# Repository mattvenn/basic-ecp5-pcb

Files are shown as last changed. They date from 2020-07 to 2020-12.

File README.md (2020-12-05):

## ECP5 FPGA dev board

* Make an ECP5 FPGA dev board
* Keep it super simple and cheap
* Configured by on-board FLASH or direct with a Raspberry Pi
* 6 PMODs, 2 buttons, 2 LEDs, FLASH for configuration bitstreams.
* buttons are active low, LEDs are active low.

There is also an iCE40 version of this board: https://github.com/mattvenn/first-fpga-pcb

## What a Lattice ecp5 FPGA needs

Check ECP5 family datasheet for more information.

* A clock input. Has to be provided by an oscillator, it doesn't have a crystal driver. Has to go to a PCLK pad
* 1.1v core supply for the internal logic. Should supply at least 600mA
* 2.5v auxiliary power supply. Should supply 10mA
* 3.3v IO supply for the IO pins. In this design, all banks of IO have the same supply. Same PSU is used for all PMODs, and is rated at 1A.
* Get configured over SPI interface. This can be done directly by a microcontroller or a computer, or the bitstream can be programmed into some FLASH, and the FPGA will read it at boot. If FLASH isn't provided then the bitstream needs to be programmed at every power up or configuration reset. See sysconfig documentation for more info.
* Decoupling capacitors for each IO bank.

## PCB

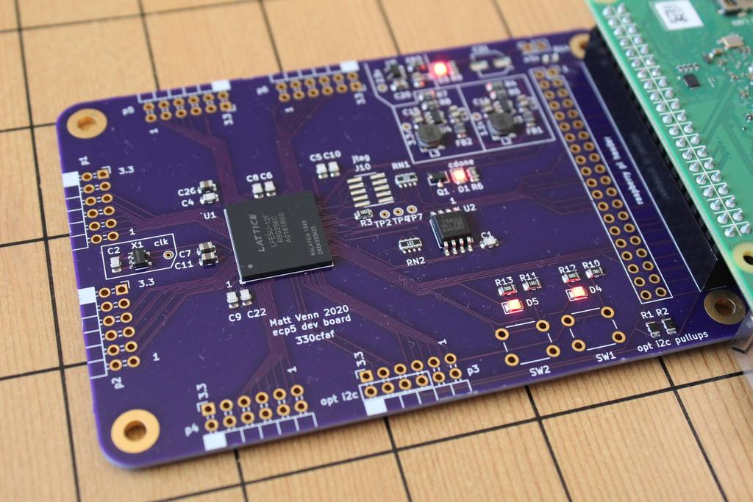
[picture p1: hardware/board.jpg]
board


* [Schematic](hardware/schematic.pdf)
* [OHSPark project](https://oshpark.com/shared_projects/pCsPoHNi) 
* [Gerbers](hardware/hardware/basic-ecp5-pcb-2020-07-20-fab.zip)

* 4 layer board stackup: signal, gnd, 3.3v, signal

## BOM

* FPGA ecp5 12k (LFE5U-12F-6BG256C) or 45k (LFE5U-45F-6BG256C) part, 14mm bga with 256 pins, 0.8mm pitch 
* 2 x TLV62568 DC/DC switchers for core (1.1v) and IO (3.3v).
* 2.5v reg TLV73325PDBVT
* 16MHz oscillator SIT2001BI-S2-33N-16.000000G
* 16MB FLASH W25Q128JVSIM (same as icebreaker)

## Design Review

* core supply (1.1v) is now DC/DC for 1A using TLV62568
* pmod and IO supply is now DC/DC for 1A using TLV62568
* move ferrite beads to input side of psu
* pullups on io2/3 of flash
* pulldown on tclk of jtag
* fix vias under bga by moving to 0.25mm drill 0.45mm annular ring
* add more ground vias under BGA

## Errata

* Add missing qspi to the Pi to be able to program bitstream faster.
* configuration bits for FPGA should be tied to gnd not through a 10k resistor. The voltage is about 1v, so might
  be a little close to the threshold of the 3.3v IOBANK supply. Replace with 0Ohm resistors? Or just tie to gnd?
* used IS25LP016D-JBLE as flash, but it has problems with enabling QE for QSPI. Relace with the model used on icebreaker
* ecp5 SPI clock pin can't be used as an input, so have to [add a bodge wire](https://github.com/mattvenn/basic-ecp5-pcb/issues/3) for SPI peripheral comms with Pi. See the test-spi-clk-in branch for a workaround.

## RPi connection info

See [test/mv_ecp.lpf](test/mv_ecp.lpf) for FPGA pinning. The following are the physical pins on the raspberry pi:

* serial: TX, RX on pins 8 and 10
* I2C: bitbanged on pins 38 and 40. Optional pullup resistors R1 & R2. Need to set up in boot/config.txt
* GPIOs: pins 31, 32, 33, 36.
* SPI: SDO, SDI, CLK, CE0 on pins 19, 21, 23, 24. These are connected to the onboard FLASH for bitstream config.
* Extra SPI CE1: pin 26 

### RPi Gotchas

* [fomu_flash will leave the SPI device in an unusable state](https://github.com/im-tomu/fomu-flash/issues/8). Run `sudo rmmod spi_bcm2835 && sudo modprobe spi_bcm2835` to reset it.
* connected I2C pins are just GPIOs. I have found the Pi's I2C hardware unusable, so always use the slower bitbanged version. 
  To enable add this to /boot/config.txt: `dtoverlay=i2c-gpio,i2c_gpio_sda=21,i2c_gpio_scl=20,i2c_gpio_delay_us=8,bus=3`

## Test: 

Simple [test](test/blinky.v) connects buttons to LEDs and toggles all other pins every second.

Yosys and NextPNR are used to create the bitstream and then it's copied to the Raspberry Pi specified
by PI_ADDR in the [Makefile](test/Makefile). 

[Fomu-Flash](https://github.com/im-tomu/fomu-flash) is used to flash the SPI memory. Clone the repo on the Pi and set
the path in the Makefile with FOMU_FLASH.

Run make in [./test](test) to build, copy and program the bitstream.

## PicoRV32 PicoSoC

I have adapted Claire Wolf's PicoRV32 Picosoc for this board: https://github.com/mattvenn/picorv32/tree/ecp5/picosoc

## Reference

* http://www.latticesemi.com/ecp5
* In particular, the ECP5 and ECP5-5G Hardware Checklist is very useful

## Inspiration

* https://github.com/Spritetm/hadbadge2019_pcb
* https://github.com/gregdavill/OrangeCrab
* https://www.crowdsupply.com/radiona/ulx3s

## Attribution

* ECP5 library part for Kicad created with https://github.com/xesscorp/KiCad-Schematic-Symbol-Libraries

## License

* Hardware is licensed under the [Permissive CERN open hardware license v2](cern_ohl_p_v2.txt)
* Software is licensed under the [GNU Lesser General Public License v2.1](LICENSE)
* Documentation is licensed under the [CCO](CC0_license)

# Open Source Hardware

This board is an OSHWA approved design: [ES000012](https://certification.oshwa.org/es000012.html)

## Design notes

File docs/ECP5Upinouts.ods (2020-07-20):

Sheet: ECP5U45Pinout
PAD | Pin/Ball Function | Bank | Dual Function | CABGA256
1 | NC | - | - | -
2 | NC | - | - | -
3 | NC | - | - | -
4 | NC | - | - | -
5 | NC | - | - | -
6 | PL11A | 7 | ULC_GPLL0T_IN | B1
7 | PL11B | 7 | ULC_GPLL0C_IN | B2
8 | VSSIO7 | - | - | -
9 | PL11C | 7 | - | C3
10 | VCCIO7 | - | - | -
11 | PL11D | 7 | - | D3
12 | PL14A | 7 | - | C1
13 | VCCAUX | - | - | -
14 | PL14C | 7 | - | E3
15 | PL14B | 7 | - | C2
16 | VSS | - | - | -
17 | PL14D | 7 | - | F3
18 | PL17A | 7 | - | D1
19 | VCC | - | - | -
20 | PL17C | 7 | - | F4
21 | PL17B | 7 | - | E2
22 | VSS | - | - | -
23 | PL17D | 7 | - | F5
24 | PL20A | 7 | - | G5
25 | VSSIO7 | - | - | -
26 | PL20C | 7 | - | F2
27 | PL20B | 7 | - | G4
28 | VCCIO7 | - | - | -
29 | PL20D | 7 | - | E1
30 | PL23A | 7 | - | F1
31 | VSSIO7 | - | - | -
32 | PL23C | 7 | VREF1_7 | G3
33 | PL23B | 7 | - | G2
34 | VCCIO7 | - | - | -
35 | PL23D | 7 | - | H3
36 | PL26A | 7 | - | H5
37 | VCCAUX | - | - | -
38 | PL26C | 7 | - | J4
39 | PL26B | 7 | - | H4
40 | VSS | - | - | -
41 | PL26D | 7 | - | J5
42 | PL29A | 7 | GR_PCLK7_1 | G1
43 | VCC | - | - | -
44 | PL29C | 7 | GR_PCLK7_0 | J3
45 | PL29B | 7 | - | H2
46 | VSS | - | - | -
47 | PL29D | 7 | - | K3
48 | PL32A | 7 | PCLKT7_1 | J1
49 | VSSIO7 | - | - | -
50 | PL32C | 7 | PCLKT7_0 | K1
51 | PL32B | 7 | PCLKC7_1 | J2
52 | VCCIO7 | - | - | -
53 | PL32D | 7 | PCLKC7_0 | K2
54 | PL35A | 6 | PCLKT6_1 | L1
55 | VSSIO6 | - | - | -
56 | PL35C | 6 | PCLKT6_0 | M1
57 | PL35B | 6 | PCLKC6_1 | L2
58 | VCCIO6 | - | - | -
59 | PL35D | 6 | PCLKC6_0 | M2
60 | PL38A | 6 | GR_PCLK6_0 | K4
61 | VCCAUX | - | - | -
62 | PL38C | 6 | GR_PCLK6_1 | L4
63 | PL38B | 6 | - | K5
64 | VSS | - | - | -
65 | PL38D | 6 | - | L5
66 | PL41A | 6 | - | N1
67 | VCC | - | - | -
68 | PL41C | 6 | - | L3
69 | PL41B | 6 | - | P2
70 | VSS | - | - | -
71 | PL41D | 6 | - | M3
72 | PL44A | 6 | - | P1
73 | VSSIO6 | - | - | -
74 | PL44C | 6 | - | M4
75 | PL44B | 6 | VREF1_6 | R1
76 | VCCIO6 | - | - | -
77 | PL44D | 6 | - | N3
78 | PL47A | 6 | - | -
79 | VSSIO6 | - | - | -
80 | PL47C | 6 | - | -
81 | PL47B | 6 | - | -
82 | VCCIO6 | - | - | -
83 | PL47D | 6 | - | -
84 | PL50A | 6 | - | -
85 | VCCAUX | - | - | -
86 | PL50C | 6 | - | -
87 | PL50B | 6 | - | -
88 | VSS | - | - | -
89 | PL50D | 6 | - | -
90 | PL53A | 6 | - | -
91 | VCC | - | - | -
92 | PL53C | 6 | - | -
93 | PL53B | 6 | - | -
94 | VSS | - | - | -
95 | PL53D | 6 | - | -
96 | PL56A | 6 | - | -
97 | VSSIO6 | - | - | -
98 | PL56C | 6 | - | -
99 | PL56B | 6 | - | -
100 | VCCIO6 | - | - | -
101 | PL56D | 6 | - | -
102 | PL59A | 6 | - | N4
103 | VSSIO6 | - | - | -
104 | PL59C | 6 | - | R2
105 | PL59B | 6 | - | P3
106 | VCCIO6 | - | - | -
107 | PL59D | 6 | - | T2
108 | PL62A | 6 | - | P4
109 | VCCAUX | - | - | -
110 | PL62C | 6 | - | R4
111 | PL62B | 6 | - | R3
112 | VSS | - | - | -
113 | PL62D | 6 | - | T3
114 | PL65A | 6 | - | R5
115 | VCC | - | - | -
116 | PL65C | 6 | - | M5
117 | PL65B | 6 | - | T4
118 | VSS | - | - | -
119 | PL65D | 6 | - | N5
120 | PL68A | 6 | - | M6
121 | VSSIO6 | - | - | -
122 | PL68B | 6 | - | N6
123 | VCCIO6 | - | - | -
124 | PL68C | 6 | LLC_GPLL0T_IN | P6
125 | PL68D | 6 | LLC_GPLL0C_IN | P5
126 | NC | - | - | -
127 | NC | - | - | -
128 | GND | - | - | -
129 | VCC | - | - | -
130 | VCC | - | - | -
131 | VSS | - | - | -
132 | PB4A | 8 | D7/IO7 | T6
133 | PB6A | 8 | D5/MISO2/IO5 | R7
134 | VCC | - | - | -
135 | PB4B | 8 | D6/IO6 | R6
136 | PB6B | 8 | D4/MOSI2/IO4 | P7
137 | VSS | - | - | -
138 | PB9A | 8 | D3/IO3 | N7
139 | PB11A | 8 | D1/MISO/IO1 | T7
140 | VSSIO8 | - | - | -
141 | PB9B | 8 | D2/IO2 | M7
142 | PB11B | 8 | D0/MOSI/IO0 | T8
143 | VCCIO8 | - | - | -
144 | PB13A | 8 | SN/CSN | R8
145 | PB15A | 8 | HOLDN/DI/BUSY/CSSPIN/CEN | N8
146 | VSSIO8 | - | - | -
147 | PB13B | 8 | CS1N | P8
148 | PB15B | 8 | DOUT/CSON | M8
149 | VCCIO8 | - | - | -
150 | PB18A | 8 | WRITEN | M9
151 | INITN | 8 | - | T9
152 | VCCAUX | - | - | -
153 | CCLK | 8 | MCLK/SCK | N9
154 | PROGRAMN | 8 | - | R9
155 | VSS | - | - | -
156 | DONE | 8 | - | P9
157 | CFG_1 | 8 | - | P10
158 | VCC | - | - | -
159 | CFG_2 | 8 | - | R10
160 | CFG_0 | 8 | - | N10
161 | VSS | - | - | -
162 | TDO | 40 | - | M10
163 | TCK | 40 | - | T10
164 | VSSIO8 | - | - | -
165 | TDI | 40 | - | R11
166 | TMS | 40 | - | T11
167 | VCCIO8 | - | - | -
168 | VCC | - | - | -
169 | VCC | - | - | -
170 | VSS | - | - | -
171 | VSS | - | - | -
172 | VCC | - | - | -
173 | VCC | - | - | -
174 | GND | - | - | -
175 | GND | - | - | -
176 | RESERVED | - | - | -
177 | GND | - | - | -
178 | RESERVED | - | - | -
179 | GND | - | - | -
180 | GND | - | - | -
181 | GND | - | - | -
182 | GND | - | - | -
183 | GND | - | - | -
184 | GND | - | - | -
185 | GND | - | - | -
186 | GND | - | - | -
187 | GND | - | - | -
188 | GND | - | - | -
189 | GND | - | - | -
190 | GND | - | - | -
191 | GND | - | - | -
192 | GND | - | - | -
193 | RESERVED | - | - | -
194 | GND | - | - | -
195 | RESERVED | - | - | -
196 | GND | - | - | -
197 | GND | - | - | -
198 | RESERVED | - | - | -
199 | GND | - | - | -
200 | RESERVED | - | - | -
201 | GND | - | - | -
202 | GND | - | - | -
203 | GND | - | - | -
204 | GND | - | - | -
205 | GND | - | - | -
206 | GND | - | - | -
207 | GND | - | - | -
208 | RESERVED | - | - | -
209 | GND | - | - | -
210 | RESERVED | - | - | -
211 | GND | - | - | -
212 | GND | - | - | -
213 | GND | - | - | -
214 | GND | - | - | -
215 | GND | - | - | -
216 | GND | - | - | -
217 | GND | - | - | -
218 | GND | - | - | -
219 | GND | - | - | -
220 | GND | - | - | -
221 | GND | - | - | -
222 | GND | - | - | -
223 | GND | - | - | -
224 | GND | - | - | -
225 | RESERVED | - | - | -
226 | GND | - | - | -
227 | RESERVED | - | - | -
228 | GND | - | - | -
229 | GND | - | - | -
230 | RESERVED | - | - | -
231 | GND | - | - | -
232 | RESERVED | - | - | -
233 | GND | - | - | -
234 | GND | - | - | -
235 | GND | - | - | -
236 | GND | - | - | -
237 | GND | - | - | -
238 | GND | - | - | -
239 | VSS | - | - | -
240 | VCC | - | - | -
241 | VCC | - | - | -
242 | NC | - | - | -
243 | NC | - | - | -
244 | PR68D | 3 | LRC_GPLL0C_IN | P12
245 | PR68C | 3 | LRC_GPLL0T_IN | P11
246 | VCCIO3 | - | - | -
247 | PR68B | 3 | - | N11
248 | VSSIO3 | - | - | -
249 | PR68A | 3 | - | M11
250 | PR65D | 3 | - | N12
251 | VSS | - | - | -
252 | PR65B | 3 | - | T13
253 | PR65C | 3 | - | M12
254 | VCC | - | - | -
255 | PR65A | 3 | - | R12
256 | PR62D | 3 | - | T14
257 | VSS | - | - | -
258 | PR62B | 3 | - | R14
259 | PR62C | 3 | - | R13
260 | VCCAUX | - | - | -
261 | PR62A | 3 | - | P13
262 | PR59D | 3 | - | T15
263 | VCCIO3 | - | - | -
264 | PR59B | 3 | - | P14
265 | PR59C | 3 | - | R15
266 | VSSIO3 | - | - | -
267 | PR59A | 3 | - | N13
268 | PR56D | 3 | - | -
269 | VCCIO3 | - | - | -
270 | PR56B | 3 | - | -
271 | PR56C | 3 | - | -
272 | VSSIO3 | - | - | -
273 | PR56A | 3 | - | -
274 | PR53D | 3 | - | -
275 | VSS | - | - | -
276 | PR53B | 3 | - | -
277 | PR53C | 3 | - | -
278 | VCC | - | - | -
279 | PR53A | 3 | - | -
280 | PR50D | 3 | - | -
281 | VSS | - | - | -
282 | PR50B | 3 | - | -
283 | PR50C | 3 | - | -
284 | VCCAUX | - | - | -
285 | PR50A | 3 | - | -
286 | PR47D | 3 | - | -
287 | VCCIO3 | - | - | -
288 | PR47B | 3 | - | -
289 | PR47C | 3 | - | -
290 | VSSIO3 | - | - | -
291 | PR47A | 3 | - | -
292 | PR44D | 3 | - | N14
293 | VCCIO3 | - | - | -
294 | PR44B | 3 | VREF1_3 | R16
295 | PR44C | 3 | - | M13
296 | VSSIO3 | - | - | -
297 | PR44A | 3 | - | P16
298 | PR41D | 3 | - | M14
299 | VSS | - | - | -
300 | PR41B | 3 | - | P15
301 | PR41C | 3 | - | L14
302 | VCC | - | - | -
303 | PR41A | 3 | - | N16
304 | PR38D | 3 | - | L12
305 | VSS | - | - | -
306 | PR38B | 3 | - | K12
307 | PR38C | 3 | GR_PCLK3_1 | L13
308 | VCCAUX | - | - | -
309 | PR38A | 3 | GR_PCLK3_0 | K13
310 | PR35D | 3 | PCLKC3_0 | M15
311 | VCCIO3 | - | - | -
312 | PR35B | 3 | PCLKC3_1 | L15
313 | PR35C | 3 | PCLKT3_0 | M16
314 | VSSIO3 | - | - | -
315 | PR35A | 3 | PCLKT3_1 | L16
316 | PR32D | 2 | PCLKC2_0 | K15
317 | VCCIO2 | - | - | -
318 | PR32B | 2 | PCLKC2_1 | J15
319 | PR32C | 2 | PCLKT2_0 | K16
320 | VSSIO2 | - | - | -
321 | PR32A | 2 | PCLKT2_1 | J16
322 | PR29D | 2 | - | K14
323 | VSS | - | - | -
324 | PR29B | 2 | - | H15
325 | PR29C | 2 | GR_PCLK2_0 | J14
326 | VCC | - | - | -
327 | PR29A | 2 | GR_PCLK2_1 | G16
328 | PR26D | 2 | - | J12
329 | VSS | - | - | -
330 | PR26B | 2 | - | H13
331 | PR26C | 2 | - | J13
332 | VCCAUX | - | - | -
333 | PR26A | 2 | - | H12
334 | PR23D | 2 | - | H14
335 | VCCIO2 | - | - | -
336 | PR23B | 2 | - | G15
337 | PR23C | 2 | VREF1_2 | G14
338 | VSSIO2 | - | - | -
339 | PR23A | 2 | - | F16
340 | PR20D | 2 | - | E16
341 | VCCIO2 | - | - | -
342 | PR20B | 2 | - | G13
343 | PR20C | 2 | - | F15
344 | VSSIO2 | - | - | -
345 | PR20A | 2 | - | G12
346 | PR17D | 2 | - | F12
347 | VSS | - | - | -
348 | PR17B | 2 | - | E15
349 | PR17C | 2 | - | F13
350 | VCC | - | - | -
351 | PR17A | 2 | - | D16
352 | PR14D | 2 | - | F14
353 | VSS | - | - | -
354 | PR14B | 2 | - | C15
355 | PR14C | 2 | - | E14
356 | VCCAUX | - | - | -
357 | PR14A | 2 | - | C16
358 | PR11D | 2 | - | D14
359 | VCCIO2 | - | - | -
360 | PR11C | 2 | - | C14
361 | VSSIO2 | - | - | -
362 | PR11B | 2 | URC_GPLL0C_IN | B15
363 | PR11A | 2 | URC_GPLL0T_IN | B16
364 | NC | - | - | -
365 | NC | - | - | -
366 | NC | - | - | -
367 | NC | - | - | -
368 | NC | - | - | -
369 | GND | - | - | -
370 | VCC | - | - | -
371 | VSS | - | - | -
372 | VCC | - | - | -
373 | PT85B | 1 | URC_GPLL1C_IN | A15
374 | VCCIO1 | - | - | -
375 | PT83B | 1 | - | A14
376 | PT85A | 1 | URC_GPLL1T_IN | B14
377 | VSSIO1 | - | - | -
378 | PT83A | 1 | - | A13
379 | PT80B | 1 | - | E13
380 | VSS | - | - | -
381 | PT78B | 1 | - | C13
382 | PT80A | 1 | - | D13
383 | VCC | - | - | -
384 | PT78A | 1 | - | B13
385 | PT76B | 1 | - | E12
386 | VSS | - | - | -
387 | PT74B | 1 | - | C12
388 | PT76A | 1 | - | D12
389 | VCCAUX | - | - | -
390 | PT74A | 1 | - | B12
391 | PT71B | 1 | - | A12
392 | VCCIO1 | - | - | -
393 | PT69B | 1 | - | E11
394 | PT71A | 1 | - | A11
395 | VSSIO1 | - | - | -
396 | PT69A | 1 | - | D11
397 | PT67B | 1 | - | -
398 | VCCIO1 | - | - | -
399 | PT65B | 1 | - | -
400 | PT67A | 1 | - | -
401 | VSSIO1 | - | - | -
402 | PT65A | 1 | - | -
403 | PT62B | 1 | - | -
404 | VSS | - | - | -
405 | PT60B | 1 | - | -
406 | PT62A | 1 | - | -
407 | VCC | - | - | -
408 | PT60A | 1 | - | -
409 | PT58B | 1 | - | C11
410 | VSS | - | - | -
411 | PT56B | 1 | - | E10
412 | PT58A | 1 | - | B11
413 | VCCAUX | - | - | -
414 | PT56A | 1 | - | D10
415 | PT53B | 1 | - | C10
416 | VCCIO1 | - | - | -
417 | PT51B | 1 | - | A10
418 | PT53A | 1 | - | B10
419 | VSSIO1 | - | - | -
420 | PT51A | 1 | - | A9
421 | PT49B | 1 | - | E9
422 | VCCIO1 | - | - | -
423 | PT47B | 1 | GR_PCLK1_1 | C9
424 | PT49A | 1 | - | D9
425 | VSSIO1 | - | - | -
426 | PT47A | 1 | GR_PCLK1_0 | B9
427 | PT44B | 1 | PCLKC1_0 | B8
428 | VSS | - | - | -
429 | PT42B | 1 | PCLKC1_1 | D8
430 | PT44A | 1 | PCLKT1_0 | C8
431 | VCC | - | - | -
432 | PT42A | 1 | PCLKT1_1 | E8
433 | VSS | - | - | -
434 | VCC | - | - | -
435 | PT38B | 0 | PCLKC0_0 | A8
436 | VSS | - | - | -
437 | PT36B | 0 | PCLKC0_1 | B7
438 | PT38A | 0 | PCLKT0_0 | A7
439 | VCCAUX | - | - | -
440 | PT36A | 0 | PCLKT0_1 | C7
441 | PT33B | 0 | GR_PCLK0_0 | D7
442 | VCCIO0 | - | - | -
443 | PT31B | 0 | - | B6
444 | PT33A | 0 | GR_PCLK0_1 | E7
445 | VSSIO0 | - | - | -
446 | PT31A | 0 | - | C6
447 | PT29B | 0 | - | -
448 | VCCIO0 | - | - | -
449 | PT27B | 0 | - | -
450 | PT29A | 0 | - | -
451 | VSSIO0 | - | - | -
452 | PT27A | 0 | - | -
453 | PT24B | 0 | - | -
454 | VSS | - | - | -
455 | PT22B | 0 | - | -
456 | PT24A | 0 | - | -
457 | VCC | - | - | -
458 | PT22A | 0 | - | -
459 | PT20B | 0 | - | D6
460 | VSS | - | - | -
461 | PT18B | 0 | - | A6
462 | PT20A | 0 | - | E6
463 | VCCAUX | - | - | -
464 | PT18A | 0 | - | A5
465 | PT15B | 0 | - | B5
466 | VCCIO0 | - | - | -
467 | PT13B | 0 | - | D5
468 | PT15A | 0 | - | C5
469 | VSSIO0 | - | - | -
470 | PT13A | 0 | - | E5
471 | PT11B | 0 | - | B4
472 | VCCIO0 | - | - | -
473 | PT9B | 0 | - | D4
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

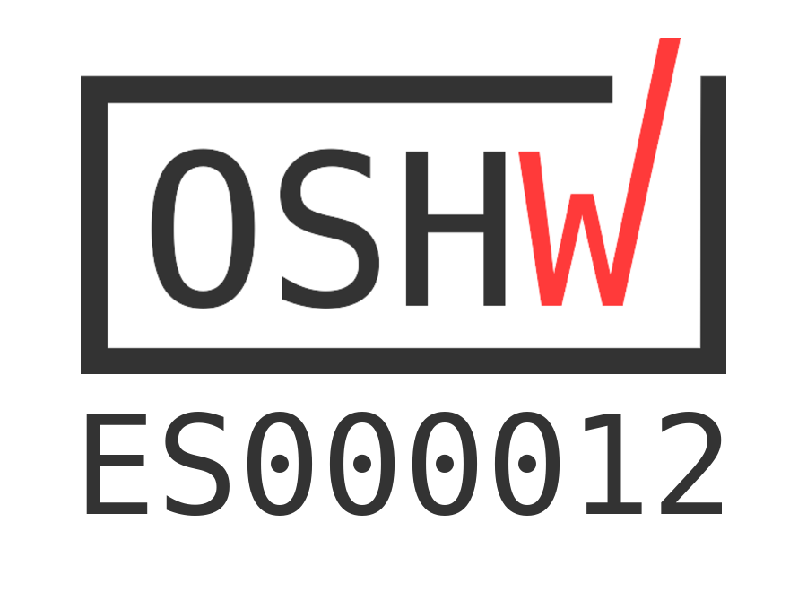
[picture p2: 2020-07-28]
docs/OSHW_mark_ES000012.png

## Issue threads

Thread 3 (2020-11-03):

spi clock input pin

mattvenn, 2020-11-03:
The ecp5 spi clock pin is used for configuration (reading SPI flash or being an SPI peripheral) and is detailed in TN1260 pdf.
The SPI clock pin is on ball N9, but this can't be used in the constraints file.

After configuration it can work as an output using the USRMCLK primitive:

```
wire tristate = 1'b0;
USRMCLK u1 (.USRMCLKI(spi_clk), .USRMCLKTS(tristate));
```

It seems it can't be used as an input. It might work with the FPGA setup as SPI peripheral: sysconfig = 001.

The board sets sysconfig to 010 as SPI controller. This is done with RN1.

workaround is to use the shared connection between raspberry pi gpio6 (pin 31) and fpga ball t6. Bridge pi gpio6 to spiclk (gpio11). Make sure that gpio6 is set to an input on the pi:

`gpio -g mode 6 in`

mattvenn, 2020-11-04:
see test-spi-clk-in branch for an example.

mattvenn, 2020-11-05:
tying raspi pins together with a direct short doesn't seem to work. but soldering a header on, and using a jumper does. This was tested on 2 boards.
so before fixing this on the board need to understand what is happening.

francis2tm, 2022-06-07:
Hello, nice work with this repo.
I think I didn't quite understand your comments. If the ECP5 is configured in Slave SPI mode (thus, the configuration SPI clock pin should be an input) it is not possible to reuse all the SPI pins after the ECP5 is configured, that is, in user mode?
I'm designing a board where the ECP5 is connected to a microcontroller via SPI and the microcontroller is the master. The objective is to use the same SPI bus to:

1. Microcontroller configures ECP5, ECP5 in Slave SPI mode
2. Data transfers ECP5 <-> Microcontroller when ECP5 is in user mode.

From your experience, is it possible?

mattvenn, 2022-06-08:
I'm sorry I can't remember. Reading my comment I think the limitation is the pin can't be used as an input. I would advise you to test before doing a board layout.

francis2tm, 2022-06-11:
thanks for the reply

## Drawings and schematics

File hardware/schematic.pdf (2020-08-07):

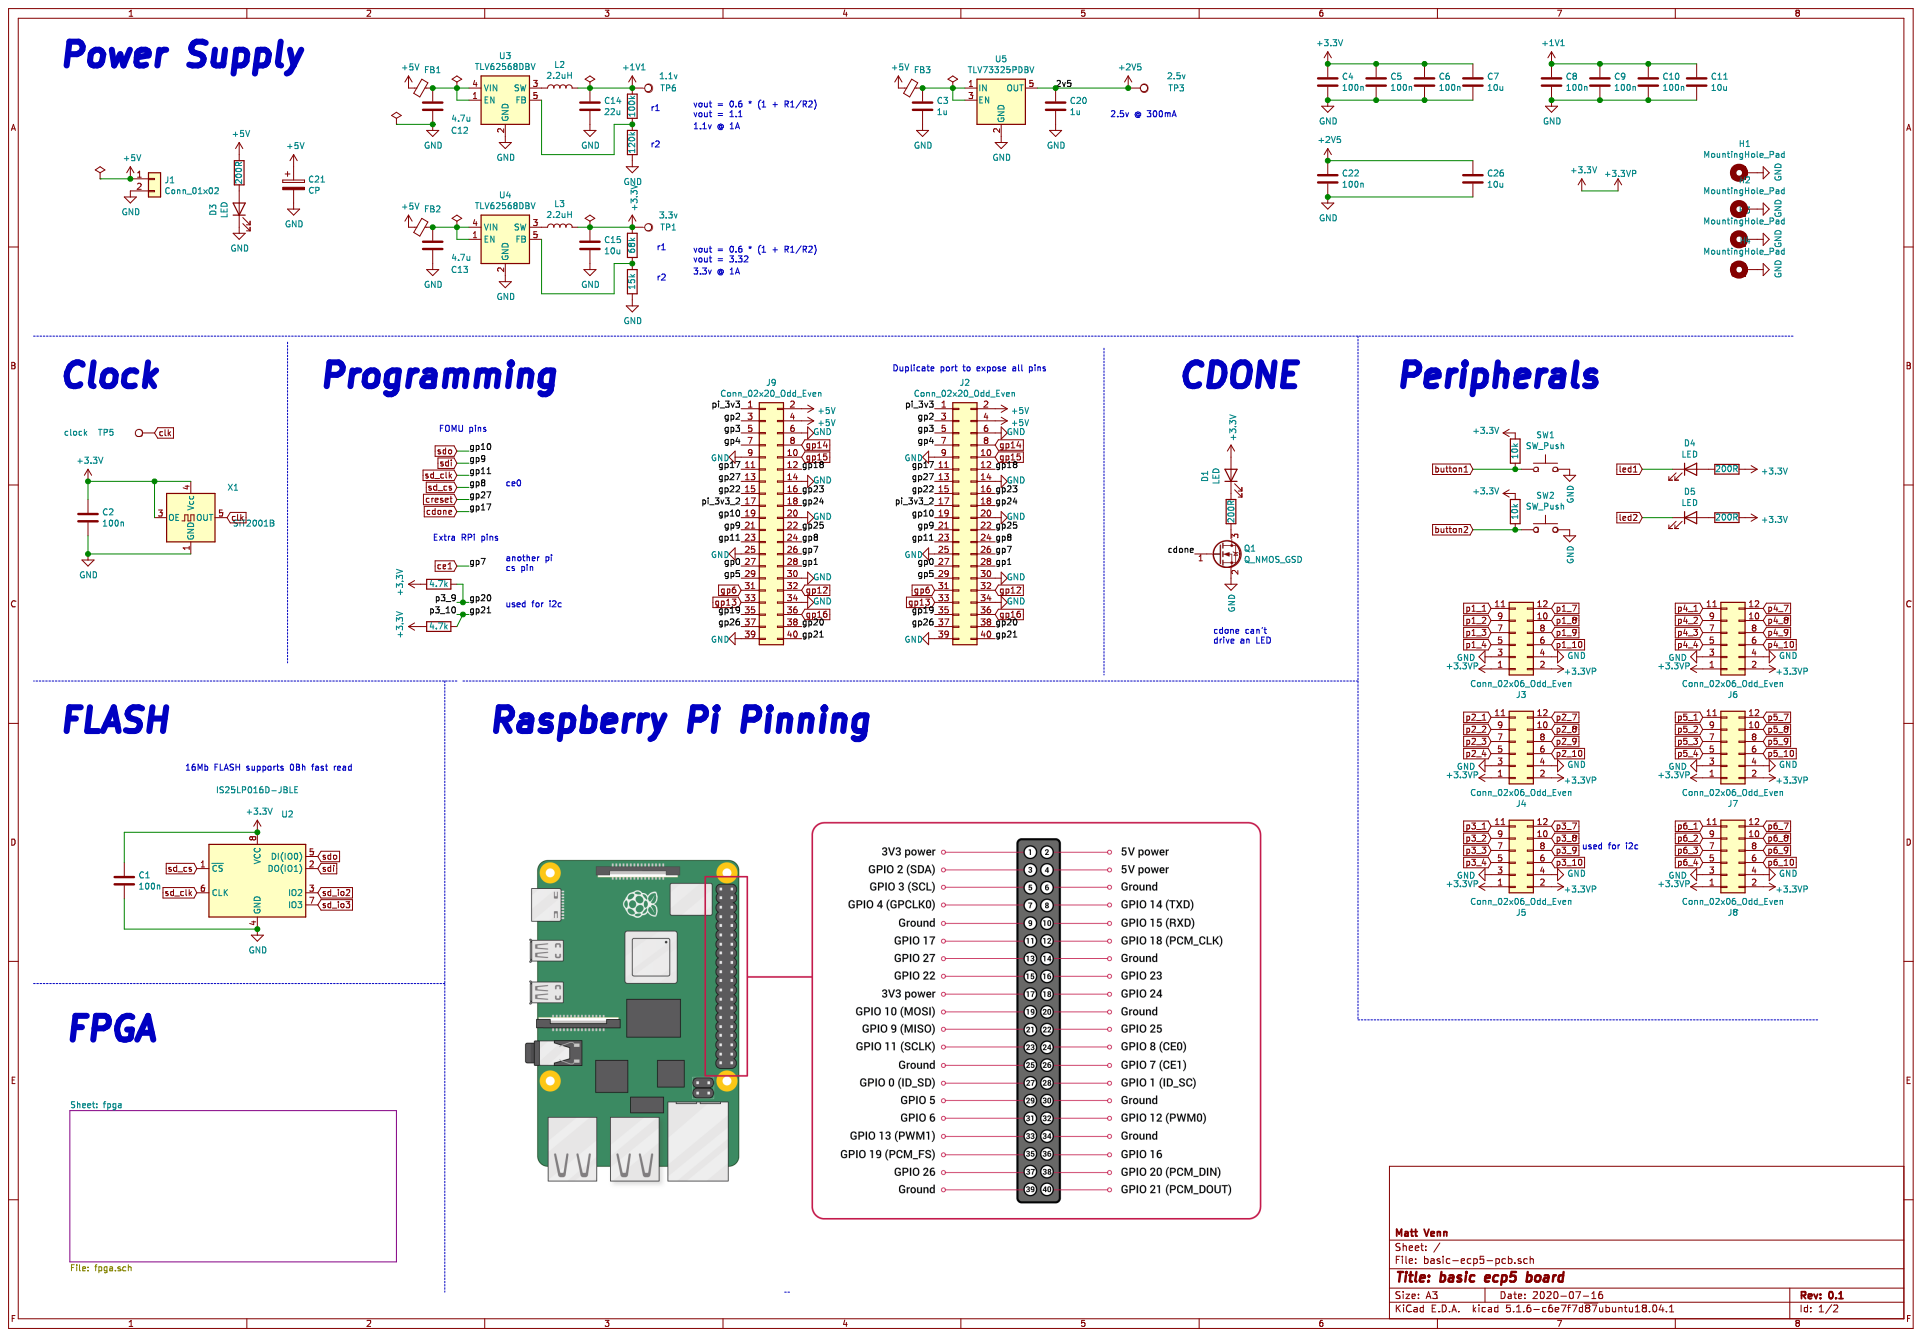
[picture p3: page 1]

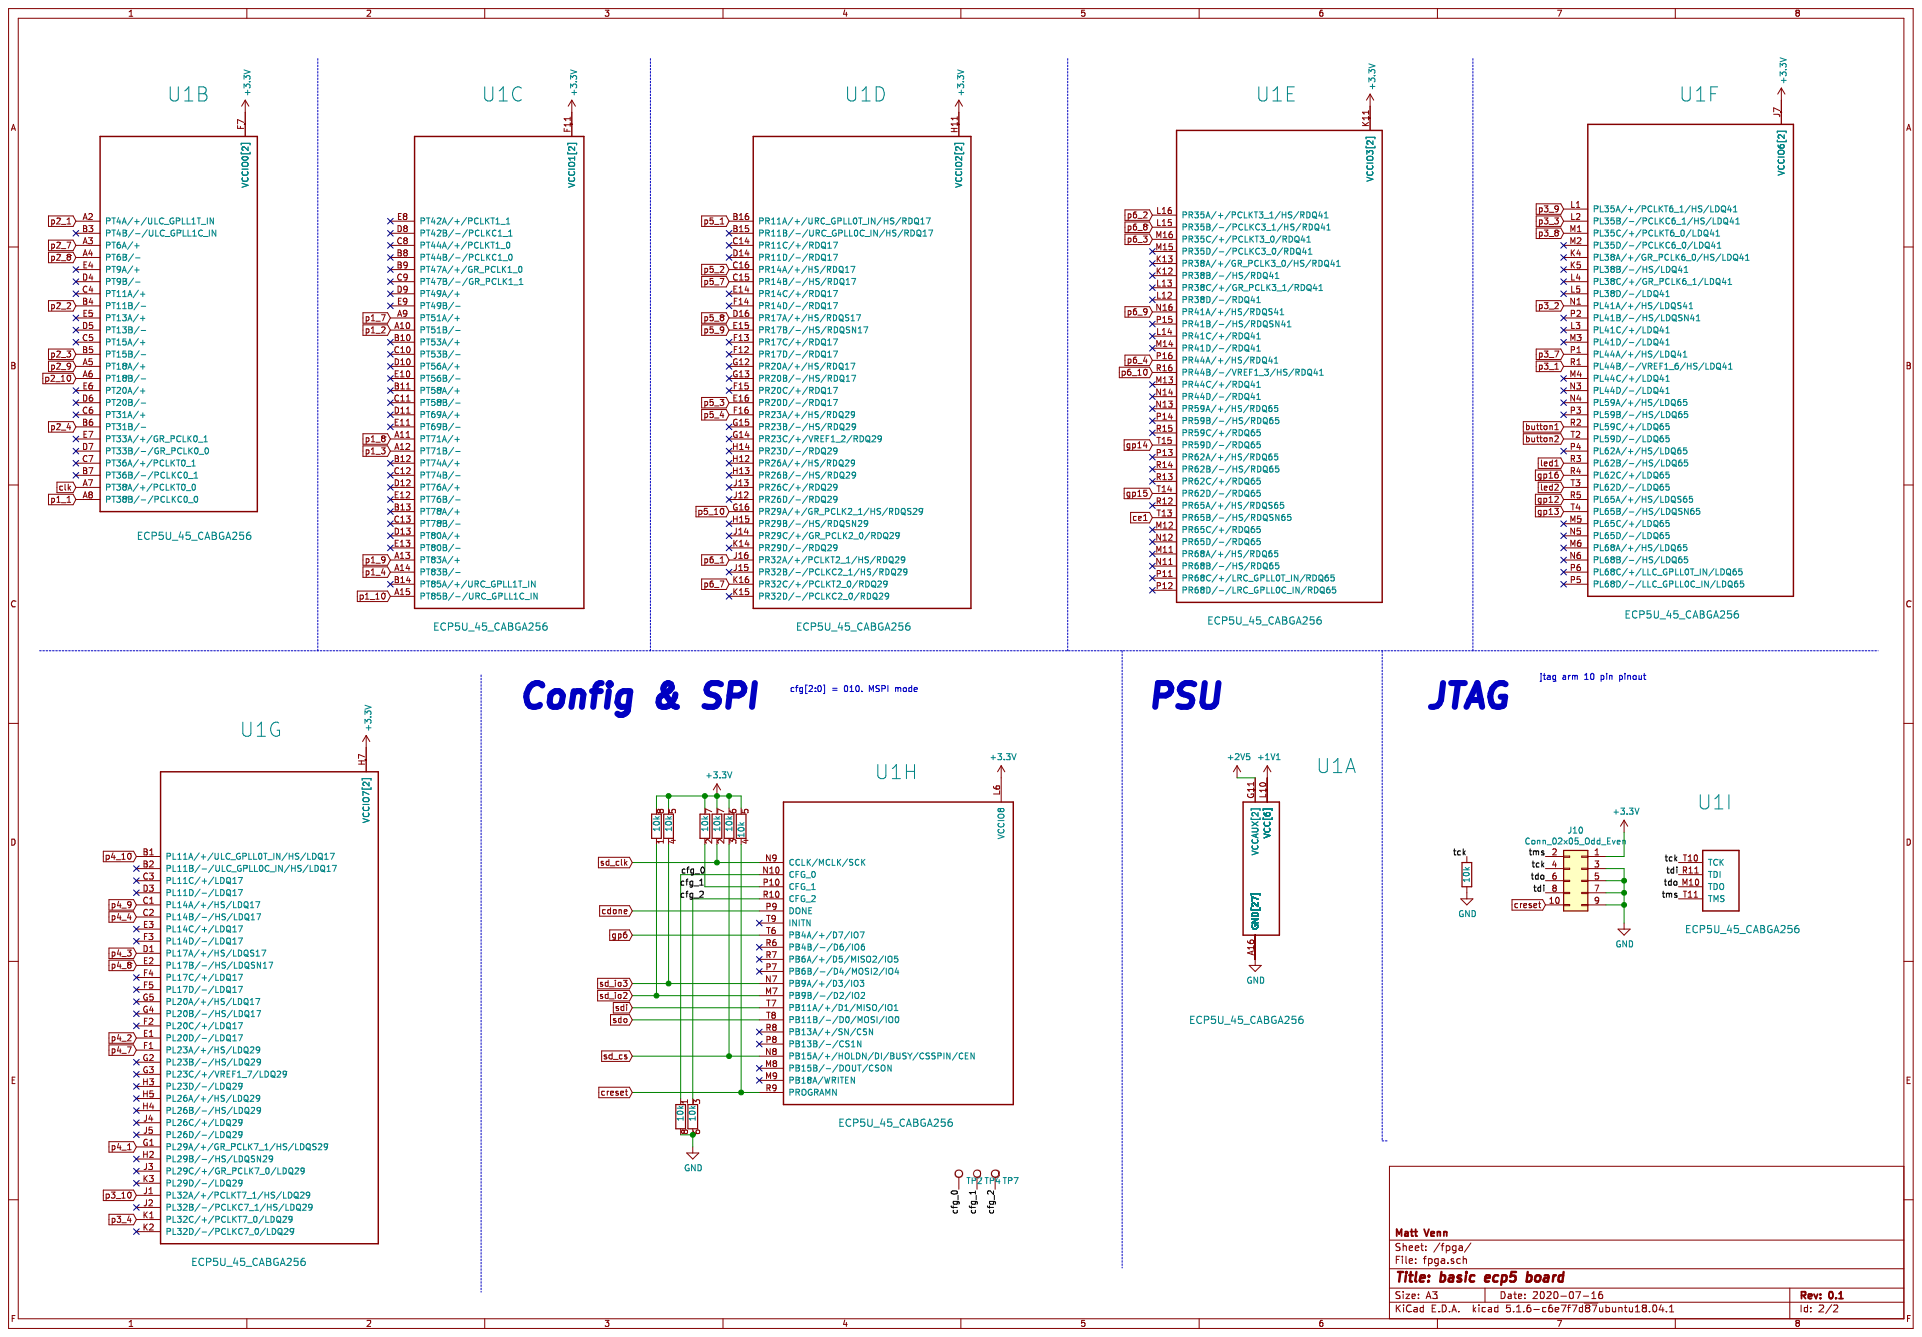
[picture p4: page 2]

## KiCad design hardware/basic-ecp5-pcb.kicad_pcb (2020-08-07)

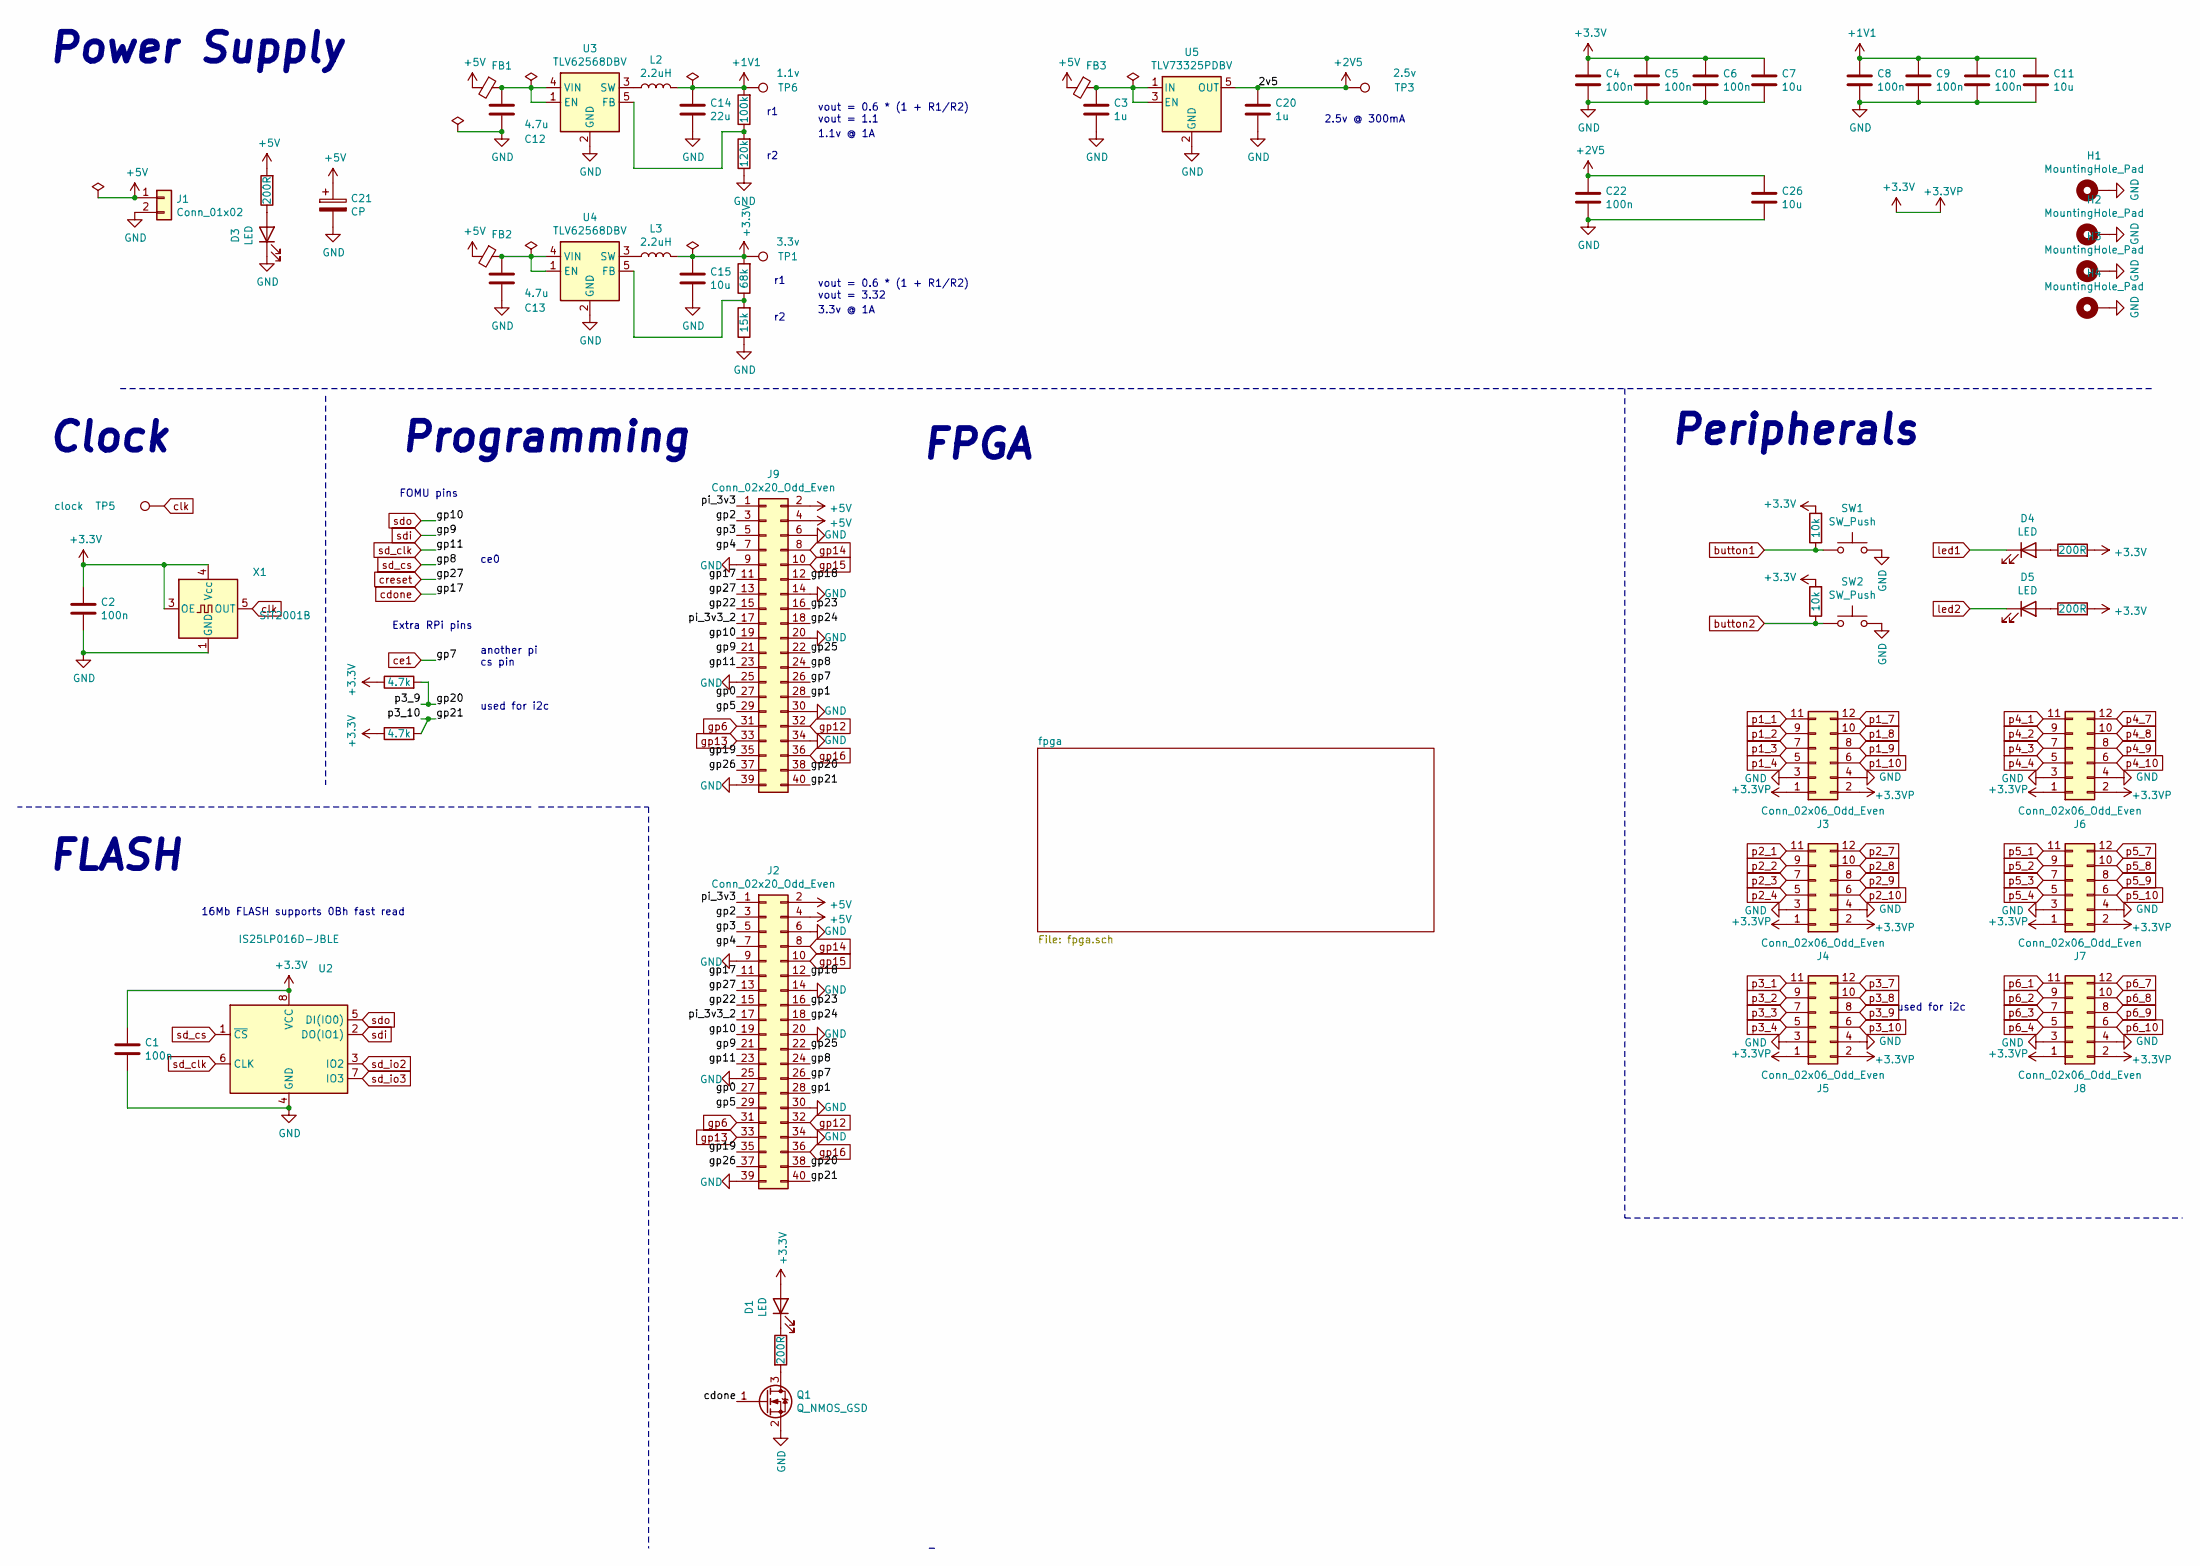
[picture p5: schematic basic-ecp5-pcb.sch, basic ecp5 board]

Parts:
C1, C2, C4, C5, C6, C8, C9, C10, C22: 100n; C_0805_2012Metric
C3, C20: 1u; C_0805_2012Metric
C7, C11, C15, C26: 10u; C_0805_2012Metric
C12, C13: 4.7u; C_0805_2012Metric
C14: 22u; C_0805_2012Metric
C21: CP; CP_Elec_5x5.4
D1, D3, D4, D5: LED; LED_0805_2012Metric
FB1, FB2, FB3: Ferrite_Bead_Small; L_0805_2012Metric
H1, H2, H3, H4: MountingHole_Pad; MountingHole_3.2mm_M3_Pad
J1: Conn_01x02; PinHeader_2x01_P2.54mm_Vertical
J2, J9: Conn_02x20_Odd_Even; PinSocket_2x20_P2.54mm_Vertical
J3, J4, J5, J6, J7, J8: Conn_02x06_Odd_Even; PinSocket_2x06_P2.54mm_Horizontal
L2, L3: 2.2uH; L_Taiyo-Yuden_NR-40xx
Q1: Q_NMOS_GSD; SOT-23
R1, R2: 4.7k; R_0805_2012Metric
R4: 100k; R_0805_2012Metric
R5: 120k; R_0805_2012Metric
R6, R9, R12, R13: 200R; R_0805_2012Metric
R7: 68k; R_0805_2012Metric
R8: 15k; R_0805_2012Metric
R10, R11: 10k; R_0805_2012Metric
SW1, SW2: SW_Push; SW_PUSH_6mm
TP1: 3.3v; TestPoint_THTPad_D1.0mm_Drill0.5mm
TP3: 2.5v; TestPoint_THTPad_D1.0mm_Drill0.5mm
TP5: clock; TestPoint_THTPad_D1.0mm_Drill0.5mm
TP6: 1.1v; TestPoint_THTPad_D1.0mm_Drill0.5mm
U2: IS25LP016D-JBLE; SOIC-8_5.23x5.23mm_P1.27mm
U3, U4: TLV62568DBV; SOT-23-5
U5: TLV73325PDBV; SOT-23-5
X1: SiT2001B; SOT-23-5

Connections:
+1V1: C8.1, C9.1, C10.1, C11.1, C14.1, L2.2, R4.2, TP6.1; also elsewhere on the board
+2V5: C20.1, C22.1, C26.1, TP3.1, U5.5 (OUT); also elsewhere on the board
+3.3VP: C1.1, C2.1, C4.1, C5.1, C6.1, C7.1, C15.1, D1.2 (A), J3.1, J3.2, J4.1, J4.2, J5.1, J5.2, J6.1, J6.2, J7.1, J7.2, J8.1, J8.2, L3.2, R1.1, R2.1, R7.2, R10.2, R11.2, R12.2, R13.2, TP1.1, U2.8 (VCC), X1.3 (OE), X1.4 (Vcc); also elsewhere on the board
+5V: C21.1, FB1.2, FB2.2, FB3.2, J1.1, J2.2, J2.4, J9.2, J9.4, R9.2
/gp0: J2.27, J9.27
/gp1: J2.28, J9.28
/gp2: J2.3, J9.3
/gp3: J2.5, J9.5
/gp4: J2.7, J9.7
/gp5: J2.29, J9.29
/gp18: J2.12, J9.12
/gp19: J2.35, J9.35
/gp22: J2.15, J9.15
/gp23: J2.16, J9.16
/gp24: J2.18, J9.18
/gp25: J2.22, J9.22
/gp26: J2.37, J9.37
/pi_3v3: J2.1, J9.1
/pi_3v3_2: J2.17, J9.17
GND: C1.2, C2.2, C3.2, C4.2, C5.2, C6.2, C7.2, C8.2, C9.2, C10.2, C11.2, C12.2, C13.2, C14.2, C15.2, C20.2, C21.2, C22.2, C26.2, D3.1 (K), H1.1, H2.1, H3.1, H4.1, J1.2, J2.6, J2.9, J2.14, J2.20, J2.25, J2.30, J2.34, J2.39, J3.3, J3.4, J4.3, J4.4, J5.3, J5.4, J6.3, J6.4, J7.3, J7.4, J8.3, J8.4, J9.6, J9.9, J9.14, J9.20, J9.25, J9.30, J9.34, J9.39, Q1.2 (S), R5.1, R8.1, SW1.2, SW2.2, U2.4 (GND), U3.2 (GND), U4.2 (GND), U5.2 (GND), X1.1 (GND); also elsewhere on the board
unnamed: C3.1, FB3.1, U5.1 (IN), U5.3 (EN)
unnamed: C12.1, FB1.1, U3.1 (EN), U3.4 (VIN)
unnamed: C13.1, FB2.1, U4.1 (EN), U4.4 (VIN)
unnamed: D1.1 (K), R6.1
unnamed: D3.2 (A), R9.1
unnamed: D4.2 (A), R12.1
unnamed: D5.2 (A), R13.1
unnamed: L2.1, U3.3 (SW)
unnamed: L3.1, U4.3 (SW)
unnamed: Q1.3 (D), R6.2
unnamed: R4.1, R5.2, U3.5 (FB)
unnamed: R7.1, R8.2, U4.5 (FB)
button1: R10.1, SW1.1; also elsewhere on the board
button2: R11.1, SW2.1; also elsewhere on the board
cdone: J2.11, J9.11, Q1.1 (G); also elsewhere on the board
ce1: J2.26, J9.26; also elsewhere on the board
clk: TP5.1, X1.5 (OUT); also elsewhere on the board
creset: J2.13, J9.13; also elsewhere on the board
gp6: J2.31, J9.31; also elsewhere on the board
gp12: J2.32, J9.32; also elsewhere on the board
gp13: J2.33, J9.33; also elsewhere on the board
gp14: J2.8, J9.8; also elsewhere on the board
gp15: J2.10, J9.10; also elsewhere on the board
gp16: J2.36, J9.36; also elsewhere on the board
led1: D4.1 (K); also elsewhere on the board
led2: D5.1 (K); also elsewhere on the board
p1_1: J3.11; also elsewhere on the board
p1_2: J3.9; also elsewhere on the board
p1_3: J3.7; also elsewhere on the board
p1_4: J3.5; also elsewhere on the board
p1_7: J3.12; also elsewhere on the board
p1_8: J3.10; also elsewhere on the board
p1_9: J3.8; also elsewhere on the board
p1_10: J3.6; also elsewhere on the board
p2_1: J4.11; also elsewhere on the board
p2_2: J4.9; also elsewhere on the board
p2_3: J4.7; also elsewhere on the board
p2_4: J4.5; also elsewhere on the board
p2_7: J4.12; also elsewhere on the board
p2_8: J4.10; also elsewhere on the board
p2_9: J4.8; also elsewhere on the board
p2_10: J4.6; also elsewhere on the board
p3_1: J5.11; also elsewhere on the board
p3_2: J5.9; also elsewhere on the board
p3_3: J5.7; also elsewhere on the board
p3_4: J5.5; also elsewhere on the board
p3_7: J5.12; also elsewhere on the board
p3_8: J5.10; also elsewhere on the board
p3_9: J2.38, J5.8, J9.38, R1.2; also elsewhere on the board
p3_10: J2.40, J5.6, J9.40, R2.2; also elsewhere on the board
p4_1: J6.11; also elsewhere on the board
p4_2: J6.9; also elsewhere on the board
p4_3: J6.7; also elsewhere on the board
p4_4: J6.5; also elsewhere on the board
p4_7: J6.12; also elsewhere on the board
p4_8: J6.10; also elsewhere on the board
p4_9: J6.8; also elsewhere on the board
p4_10: J6.6; also elsewhere on the board
p5_1: J7.11; also elsewhere on the board
p5_2: J7.9; also elsewhere on the board
p5_3: J7.7; also elsewhere on the board
p5_4: J7.5; also elsewhere on the board
p5_7: J7.12; also elsewhere on the board
p5_8: J7.10; also elsewhere on the board
p5_9: J7.8; also elsewhere on the board
p5_10: J7.6; also elsewhere on the board
p6_1: J8.11; also elsewhere on the board
p6_2: J8.9; also elsewhere on the board
p6_3: J8.7; also elsewhere on the board
p6_4: J8.5; also elsewhere on the board
p6_7: J8.12; also elsewhere on the board
p6_8: J8.10; also elsewhere on the board
p6_9: J8.8; also elsewhere on the board
p6_10: J8.6; also elsewhere on the board
sd_clk: J2.23, J9.23, U2.6 (CLK); also elsewhere on the board
sd_cs: J2.24, J9.24, U2.1 (~CS); also elsewhere on the board
sd_io2: U2.3 (IO2); also elsewhere on the board
sd_io3: U2.7 (IO3); also elsewhere on the board
sdi: J2.21, J9.21, U2.2 (DO(IO1)); also elsewhere on the board
sdo: J2.19, J9.19, U2.5 (DI(IO0)); also elsewhere on the board

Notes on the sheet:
1.1v @ 1A
Power Supply
Clock
FLASH
Peripherals
FPGA
Programming
16Mb FLASH supports 0Bh fast read
FOMU pins
ce0
used for i2c
Extra RPi pins
another pi cs pin
2.5v @ 300mA
3.3v @ 1A
vout = 0.6 * (1 + R1/R2) vout = 3.32
vout = 0.6 * (1 + R1/R2) vout = 1.1

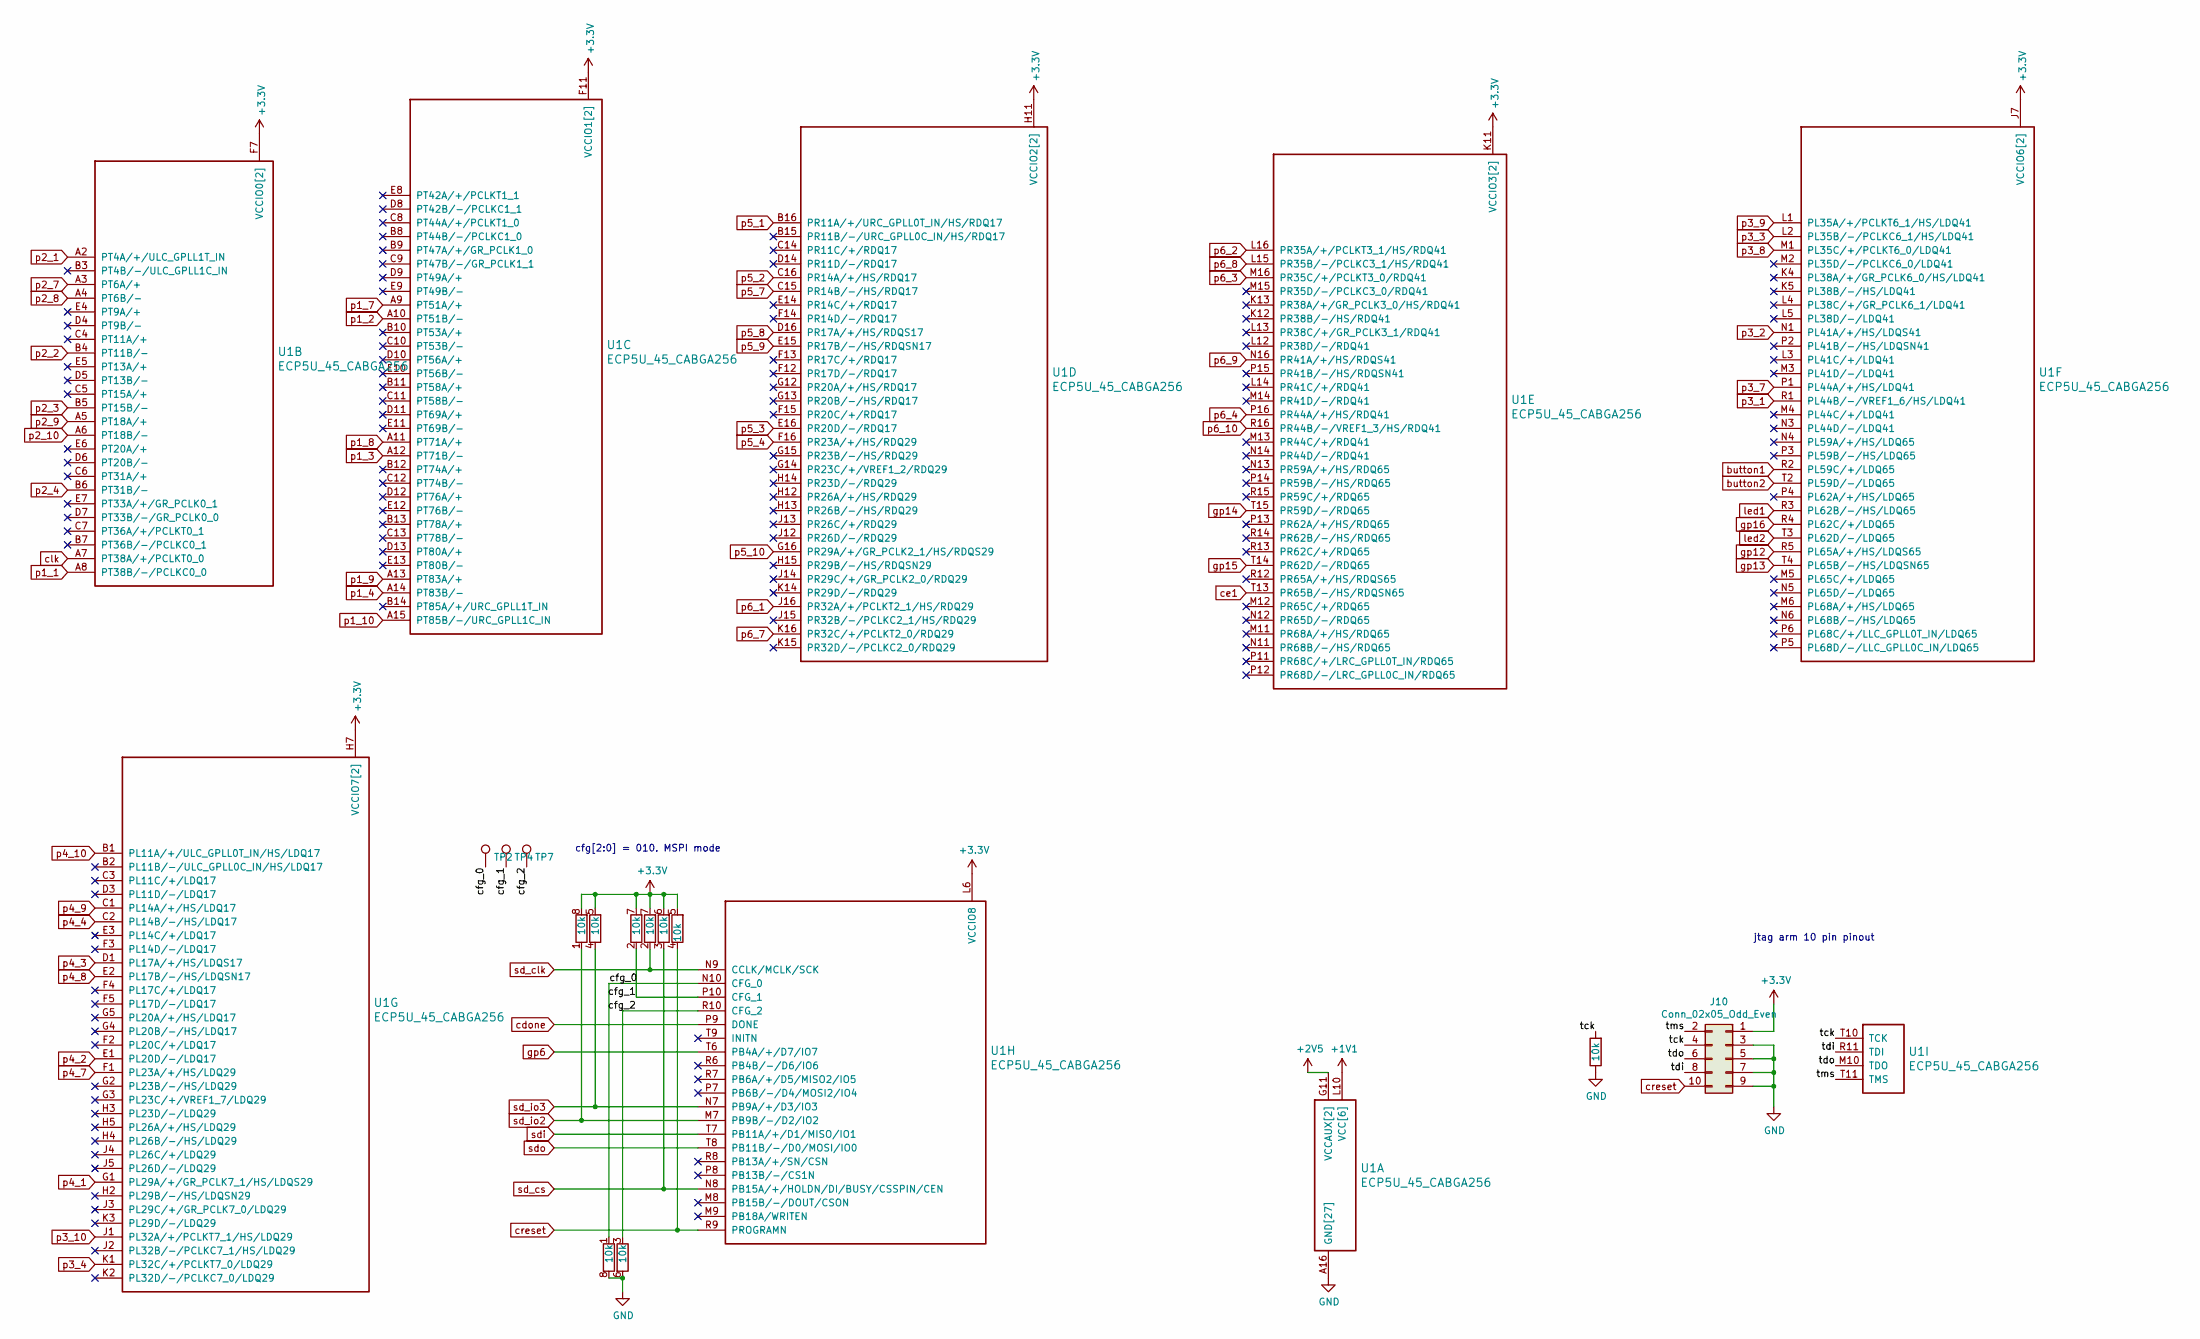
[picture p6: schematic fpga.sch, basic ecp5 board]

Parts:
J10: Conn_02x05_Odd_Even; PinHeader_2x05_P1.27mm_Vertical_SMD
R3: 10k; R_0805_2012Metric
RN1, RN2: 10k; R_Array_Concave_4x0603
TP2, TP4, TP7: TestPoint; TestPoint_THTPad_D1.0mm_Drill0.5mm
U1: ECP5U_45_CABGA256; BGA-256_14.0x14.0mm_Layout16x16_P0.8mm_Ball0.45mm_Pad0.32mm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

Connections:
+1V1: U1.G6 (VCC[6]), U1.G7 (VCC[6]), U1.G9 (VCC[6]), U1.L8 (VCC[6]), U1.L9 (VCC[6]), U1.L10 (VCC[6]); also elsewhere on the board
+2V5: U1.G11 (VCCAUX[2]), U1.L7 (VCCAUX[2]); also elsewhere on the board
+3.3VP: J10.1, RN1.5 (R4.2), RN1.7 (R2.2), RN2.5 (R4.2), RN2.6 (R3.2), RN2.7 (R2.2), RN2.8 (R1.2), U1.F6 (VCCIO0[2]), U1.F7 (VCCIO0[2]), U1.F10 (VCCIO1[2]), U1.F11 (VCCIO1[2]), U1.H6 (VCCIO7[2]), U1.H7 (VCCIO7[2]), U1.H11 (VCCIO2[2]), U1.J6 (VCCIO6[2]), U1.J7 (VCCIO6[2]), U1.J11 (VCCIO2[2]), U1.K11 (VCCIO3[2]), U1.L6 (VCCIO8), U1.L11 (VCCIO3[2]); also elsewhere on the board
/fpga/cfg_0: RN1.1 (R1.1), TP2.1, U1.N10 (CFG_0)
/fpga/cfg_1: RN1.2 (R2.1), TP4.1, U1.P10 (CFG_1)
/fpga/cfg_2: RN1.3 (R3.1), TP7.1, U1.R10 (CFG_2)
/fpga/tck: J10.4, R3.2, U1.T10 (TCK)
/fpga/tdi: J10.8, U1.R11 (TDI)
/fpga/tdo: J10.6, U1.M10 (TDO)
/fpga/tms: J10.2, U1.T11 (TMS)
GND: J10.3, J10.5, J10.7, J10.9, R3.1, RN1.6 (R3.2), RN1.8 (R1.2), U1.A1 (GND[27]), U1.A16 (GND[27]), U1.D2 (GND[27]), U1.D15 (GND[27]), U1.F8 (GND[27]), U1.F9 (GND[27]), U1.G8 (GND[27]), U1.G10 (GND[27]), U1.H1 (GND[27]), U1.H8 (GND[27]), U1.H9 (GND[27]), U1.H10 (GND[27]), U1.H16 (GND[27]), U1.J8 (GND[27]), U1.J9 (GND[27]), U1.J10 (GND[27]), U1.K6 (GND[27]), U1.K7 (GND[27]), U1.K8 (GND[27]), U1.K9 (GND[27]), U1.K10 (GND[27]), U1.N2 (GND[27]), U1.N15 (GND[27]), U1.T1 (GND[27]), U1.T5 (GND[27]), U1.T12 (GND[27]), U1.T16 (GND[27]); also elsewhere on the board
button1: U1.R2 (PL59C/+/LDQ65); also elsewhere on the board
button2: U1.T2 (PL59D/-/LDQ65); also elsewhere on the board
cdone: U1.P9 (DONE); also elsewhere on the board
ce1: U1.T13 (PR65B/-/HS/RDQSN65); also elsewhere on the board
clk: U1.A7 (PT38A/+/PCLKT0_0); also elsewhere on the board
creset: J10.10, RN1.4 (R4.1), U1.R9 (PROGRAMN); also elsewhere on the board
gp6: U1.T6 (PB4A/+/D7/IO7); also elsewhere on the board
gp12: U1.R5 (PL65A/+/HS/LDQS65); also elsewhere on the board
gp13: U1.T4 (PL65B/-/HS/LDQSN65); also elsewhere on the board
gp14: U1.T15 (PR59D/-/RDQ65); also elsewhere on the board
gp15: U1.T14 (PR62D/-/RDQ65); also elsewhere on the board
gp16: U1.R4 (PL62C/+/LDQ65); also elsewhere on the board
led1: U1.R3 (PL62B/-/HS/LDQ65); also elsewhere on the board
led2: U1.T3 (PL62D/-/LDQ65); also elsewhere on the board
p1_1: U1.A8 (PT38B/-/PCLKC0_0); also elsewhere on the board
p1_2: U1.A10 (PT51B/-); also elsewhere on the board
p1_3: U1.A12 (PT71B/-); also elsewhere on the board
p1_4: U1.A14 (PT83B/-); also elsewhere on the board
p1_7: U1.A9 (PT51A/+); also elsewhere on the board
p1_8: U1.A11 (PT71A/+); also elsewhere on the board
p1_9: U1.A13 (PT83A/+); also elsewhere on the board
p1_10: U1.A15 (PT85B/-/URC_GPLL1C_IN); also elsewhere on the board
p2_1: U1.A2 (PT4A/+/ULC_GPLL1T_IN); also elsewhere on the board
p2_2: U1.B4 (PT11B/-); also elsewhere on the board
p2_3: U1.B5 (PT15B/-); also elsewhere on the board
p2_4: U1.B6 (PT31B/-); also elsewhere on the board
p2_7: U1.A3 (PT6A/+); also elsewhere on the board
p2_8: U1.A4 (PT6B/-); also elsewhere on the board
p2_9: U1.A5 (PT18A/+); also elsewhere on the board
p2_10: U1.A6 (PT18B/-); also elsewhere on the board
p3_1: U1.R1 (PL44B/-/VREF1_6/HS/LDQ41); also elsewhere on the board
p3_2: U1.N1 (PL41A/+/HS/LDQS41); also elsewhere on the board
p3_3: U1.L2 (PL35B/-/PCLKC6_1/HS/LDQ41); also elsewhere on the board
p3_4: U1.K1 (PL32C/+/PCLKT7_0/LDQ29); also elsewhere on the board
p3_7: U1.P1 (PL44A/+/HS/LDQ41); also elsewhere on the board
p3_8: U1.M1 (PL35C/+/PCLKT6_0/LDQ41); also elsewhere on the board
p3_9: U1.L1 (PL35A/+/PCLKT6_1/HS/LDQ41); also elsewhere on the board
p3_10: U1.J1 (PL32A/+/PCLKT7_1/HS/LDQ29); also elsewhere on the board
p4_1: U1.G1 (PL29A/+/GR_PCLK7_1/HS/LDQS29); also elsewhere on the board
p4_2: U1.E1 (PL20D/-/LDQ17); also elsewhere on the board
p4_3: U1.D1 (PL17A/+/HS/LDQS17); also elsewhere on the board
p4_4: U1.C2 (PL14B/-/HS/LDQ17); also elsewhere on the board
p4_7: U1.F1 (PL23A/+/HS/LDQ29); also elsewhere on the board
p4_8: U1.E2 (PL17B/-/HS/LDQSN17); also elsewhere on the board
p4_9: U1.C1 (PL14A/+/HS/LDQ17); also elsewhere on the board
p4_10: U1.B1 (PL11A/+/ULC_GPLL0T_IN/HS/LDQ17); also elsewhere on the board
p5_1: U1.B16 (PR11A/+/URC_GPLL0T_IN/HS/RDQ17); also elsewhere on the board
p5_2: U1.C16 (PR14A/+/HS/RDQ17); also elsewhere on the board
p5_3: U1.E16 (PR20D/-/RDQ17); also elsewhere on the board
p5_4: U1.F16 (PR23A/+/HS/RDQ29); also elsewhere on the board
p5_7: U1.C15 (PR14B/-/HS/RDQ17); also elsewhere on the board
p5_8: U1.D16 (PR17A/+/HS/RDQS17); also elsewhere on the board
p5_9: U1.E15 (PR17B/-/HS/RDQSN17); also elsewhere on the board
p5_10: U1.G16 (PR29A/+/GR_PCLK2_1/HS/RDQS29); also elsewhere on the board
p6_1: U1.J16 (PR32A/+/PCLKT2_1/HS/RDQ29); also elsewhere on the board
p6_2: U1.L16 (PR35A/+/PCLKT3_1/HS/RDQ41); also elsewhere on the board
p6_3: U1.M16 (PR35C/+/PCLKT3_0/RDQ41); also elsewhere on the board
p6_4: U1.P16 (PR44A/+/HS/RDQ41); also elsewhere on the board
p6_7: U1.K16 (PR32C/+/PCLKT2_0/RDQ29); also elsewhere on the board
p6_8: U1.L15 (PR35B/-/PCLKC3_1/HS/RDQ41); also elsewhere on the board
p6_9: U1.N16 (PR41A/+/HS/RDQS41); also elsewhere on the board
p6_10: U1.R16 (PR44B/-/VREF1_3/HS/RDQ41); also elsewhere on the board
sd_clk: RN2.2 (R2.1), U1.N9 (CCLK/MCLK/SCK); also elsewhere on the board
sd_cs: RN2.3 (R3.1), U1.N8 (PB15A/+/HOLDN/DI/BUSY/CSSPIN/CEN); also elsewhere on the board
sd_io2: RN2.1 (R1.1), U1.M7 (PB9B/-/D2/IO2); also elsewhere on the board
sd_io3: RN2.4 (R4.1), U1.N7 (PB9A/+/D3/IO3); also elsewhere on the board
sdi: U1.T7 (PB11A/+/D1/MISO/IO1); also elsewhere on the board
sdo: U1.T8 (PB11B/-/D0/MOSI/IO0); also elsewhere on the board

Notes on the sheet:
jtag arm 10 pin pinout
cfg[2:0] = 010. MSPI mode

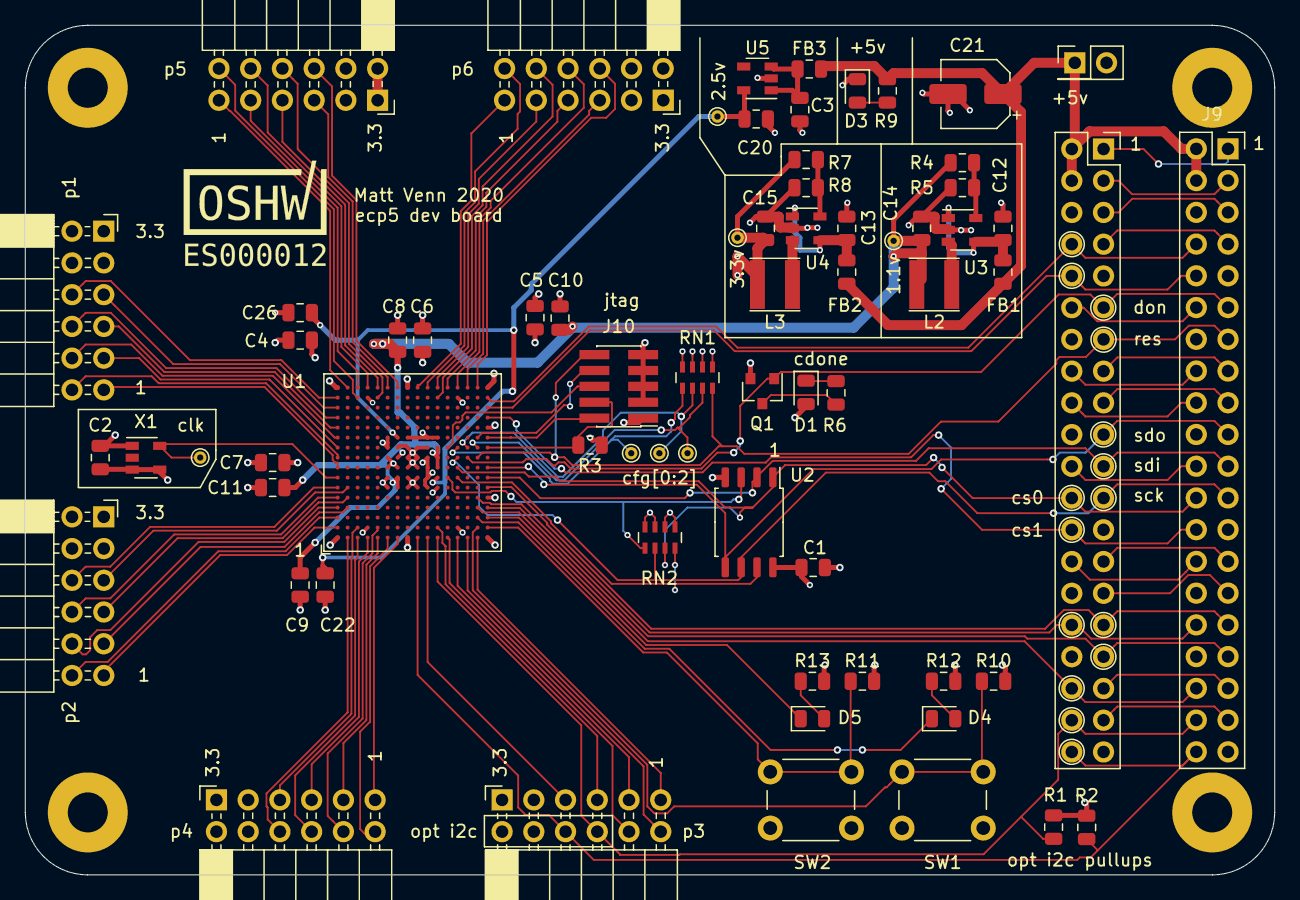
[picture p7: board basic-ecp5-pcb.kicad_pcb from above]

Board: 4 copper layers, 100.0 x 68.0 mm, 73 parts (0 on the bottom side), 107 nets.

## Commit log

2020-07-16 pmods connected and routed
    [basic-ecp5-pcb.kicad_pcb, basic-ecp5-pcb.sch, fpga.sch]
2020-07-16 gerbers, readme, schematic
2020-07-16 update page info
    [basic-ecp5-pcb.sch, fpga.sch]
2020-07-17 changes for design review (see readme)
    [basic-ecp5-pcb.kicad_pcb, basic-ecp5-pcb.sch, fpga.sch]
2020-07-17 add serial connection
    [basic-ecp5-pcb.kicad_pcb, basic-ecp5-pcb.sch, fpga.sch]
2020-07-17 updated gerbers
2020-07-17 updated schematic
2020-07-20 ready to order
    [basic-ecp5-pcb.kicad_pcb, fpga.sch]
2020-07-20 fix a couple of off centre vias in bga
    [basic-ecp5-pcb.kicad_pcb]
2020-07-20 added input R for dc/dc
    [basic-ecp5-pcb.kicad_pcb, basic-ecp5-pcb.sch]
2020-07-20 osh park gerbers
2020-07-20 part numbers and notes on dc/dc voltage dividers
    [basic-ecp5-pcb.sch, fpga.sch]
2020-07-20 ignore logs, make device a variable
2020-07-20 extra comment on spi pin
2020-07-22 fix wrong package version of switcher chip
    [basic-ecp5-pcb.sch]
2020-07-28 oshw logo
    [basic-ecp5-pcb.kicad_pcb]
2020-07-28 inductor 3d and new board pic
    [basic-ecp5-pcb.kicad_pcb]
2020-08-04 cleanup config silkscreen
    [basic-ecp5-pcb.kicad_pcb]
2020-08-04 removed unneeded pullup for PG pin on buck converters
    [basic-ecp5-pcb.kicad_pcb, basic-ecp5-pcb.sch]
2020-08-07 change 10k i2c pullups to 4k7
    [basic-ecp5-pcb.sch]
2020-08-07 remove a few stubs on copper fpga supply. improve silk
    [basic-ecp5-pcb.kicad_pcb]
2020-08-07 neaten FPGA page
    [basic-ecp5-pcb.sch, fpga.sch]
2020-08-07 neatened schematic
2020-08-11 updated to use icebreaker flash as it works easily for QE
    [basic-ecp5-pcb.sch]
2020-08-13 add attribution for kicad ecp5 libary symbols
2020-11-03 notes on spi clock issue
2020-12-05 note on leds and picosoc
